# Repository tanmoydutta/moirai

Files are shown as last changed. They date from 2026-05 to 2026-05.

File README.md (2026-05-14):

# Moirai
This is an STM32WLE5 standalone module built with Seeed Studio Wio-E5. The objective was to replace the proprietary firmware and make use of the STM32 chip to run a custom firmware which makes use of the built in SubGHz radio for specific purposes. At the back of the PCB there are interface touch pads for Software Debug interface as well as an UART debug connector pads. This module is pin compatible with ESP02S modules and ESP8685-WROOM-03 this helps to add SubGHz and LoRaWAN cpability (with proper firmware) to any existing solution built for limited WiFi and Bluetooth solutions.

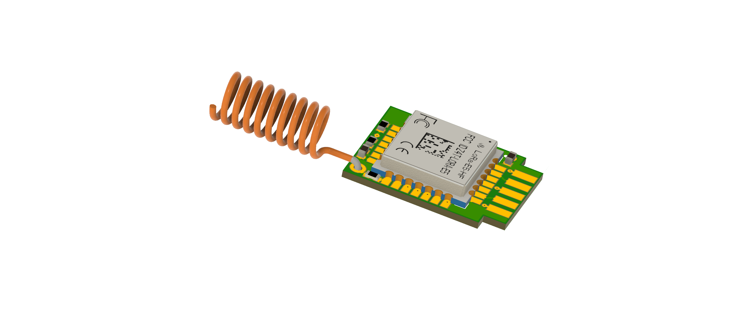
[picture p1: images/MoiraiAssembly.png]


This is a size comparison of the built module. Note that in this picture the pinout is mirrored but the actual design is done the other way.
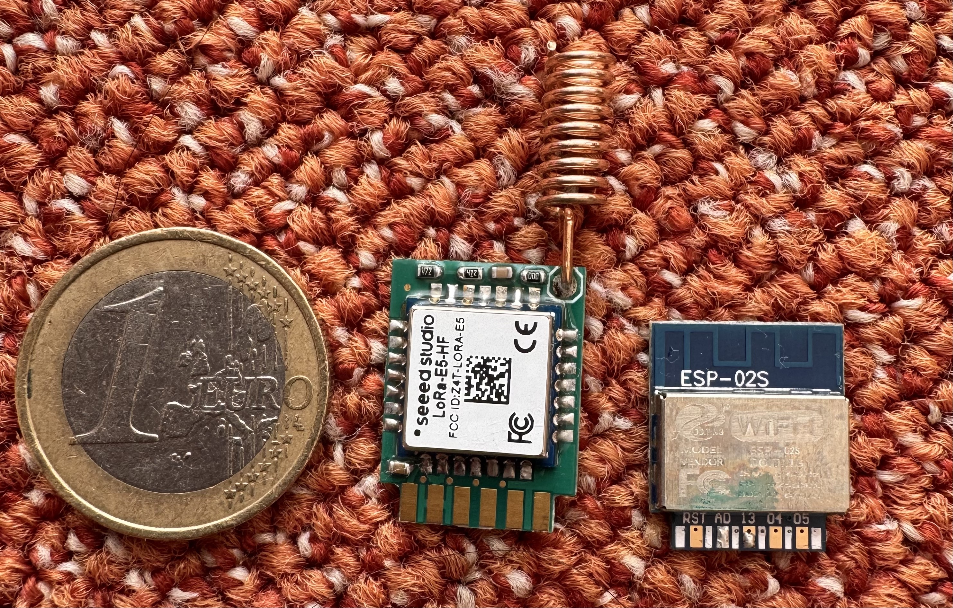
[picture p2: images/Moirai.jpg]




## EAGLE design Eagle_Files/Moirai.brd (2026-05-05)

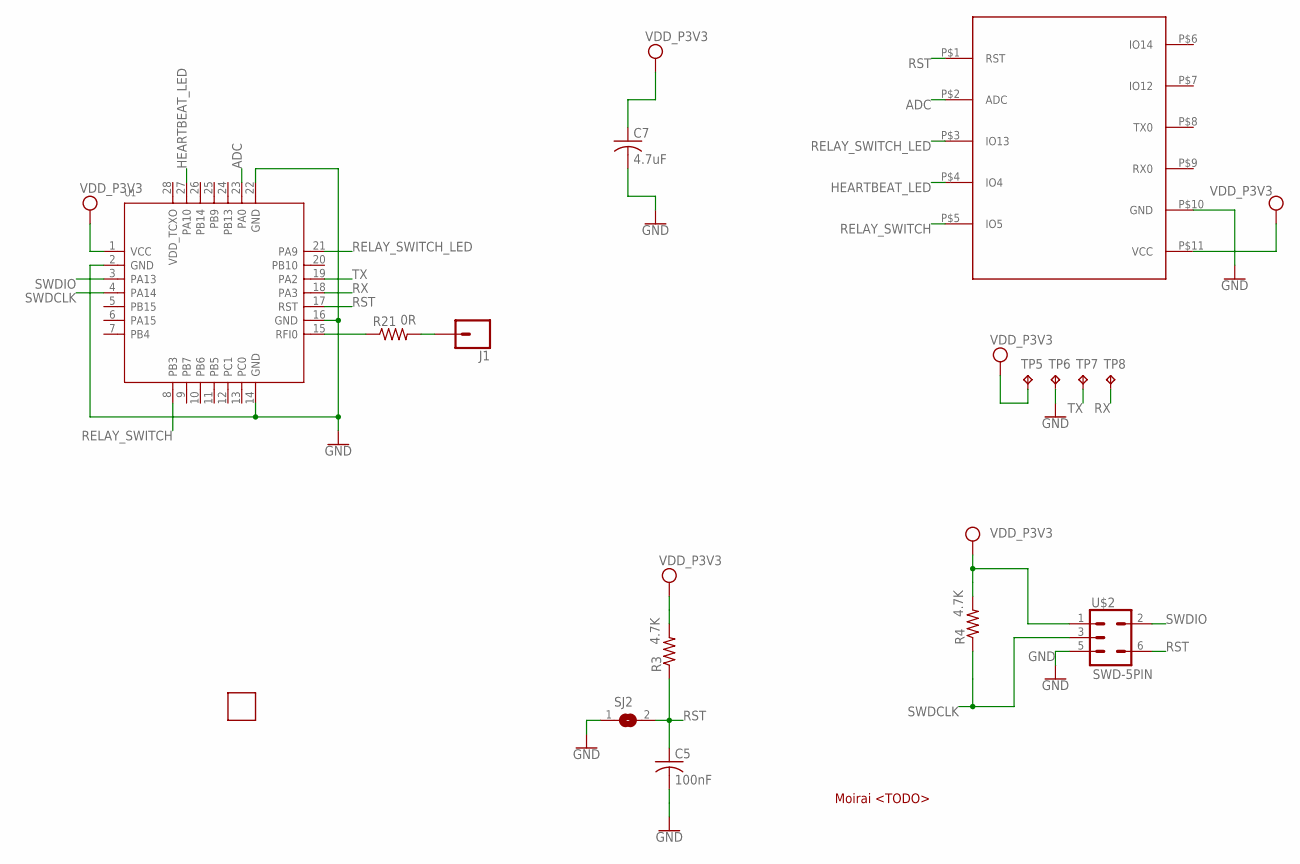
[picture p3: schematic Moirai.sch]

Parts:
C5: 100nF; C0402
C7: 4.7uF; C0402
J1: CONN_01; 1X01
R3, R4: 4.7K; R0402
R21: 0R; R0402
SJ2: SJ
TP5, TP6, TP7, TP8: TPB1,27; B1,27
U1: MODULE_LORA_E5; MODULE28P-1.25-12X12X2.5MM
U$1: ESP02SESP02S_MIRROR; ESP02S_MIRROR
U$2: SWD-5PIN; PAD_05_03X2_TP_NO4
U$3: SMARTT_SMALL

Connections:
ADC: U1.23 (PA0), U$1.P$2 (ADC)
GND: C5.2, C7.2, SJ2.1, TP6.TP, U1.2 (GND), U1.14 (GND), U1.16 (GND), U1.22 (GND), U$1.P$10 (GND), U$2.5
HEARTBEAT_LED: U1.27 (PA10), U$1.P$4 (IO4)
unnamed: R21.1, U1.15 (RFI0)
unnamed: J1.1, R21.2
RELAY_SWITCH: U1.8 (PB3), U$1.P$5 (IO5)
RELAY_SWITCH_LED: U1.21 (PA9), U$1.P$3 (IO13)
RST: C5.1, R3.1, SJ2.2, U1.17 (RST), U$1.P$1 (RST), U$2.6
RX: TP8.TP, U1.18 (PA3)
SWDCLK: R4.1, U1.4 (PA14), U$2.3
SWDIO: U1.3 (PA13), U$2.2
TX: TP7.TP, U1.19 (PA2)
VCC: C7.1, R3.2, R4.2, TP5.TP, U1.1 (VCC), U$1.P$11 (VCC), U$2.1

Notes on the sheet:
Moirai <TODO>

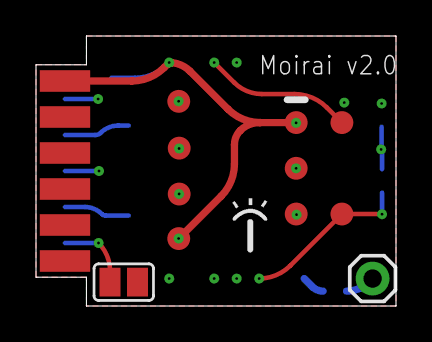
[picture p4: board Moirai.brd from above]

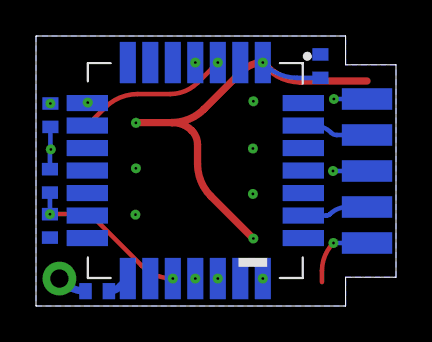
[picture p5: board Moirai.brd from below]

Board: 6 copper layers, 20.0 x 15.0 mm, 15 parts (7 on the bottom side), 13 nets.

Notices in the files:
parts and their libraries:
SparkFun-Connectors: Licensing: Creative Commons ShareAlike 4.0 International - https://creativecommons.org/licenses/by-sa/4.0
